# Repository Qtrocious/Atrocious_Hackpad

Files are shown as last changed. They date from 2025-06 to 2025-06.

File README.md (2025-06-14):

# Atrocious_Hackpad
A 3x3 macropad with a rotary encoder designed to function as a numpad and have certain layers for daily use

# But, but why tho
I saw hackpad as the perfect project for Highway to practice my skils i learned from Solder and i also learned fusion360! 
> It was painful

# CAD
CASE CAD (2)
# PCB
PCB (2)
# Schematic
SCHEMATIC (2)

# Screenshot of my case and how it'll fit together
Assembling

# BOM
| Item Name | Quantity |
|---|---|
| Cherry MX Switches |9|
| Blank DSA Keycaps |9|
| SK6812 MINI Leds |9|
| Through-hole 1N4148 Diodes |9|
| M3x16 Bolt |3| 
| M3 Heatset |3| 
| EC11 Rotary encoder |1|
| OLED .91" SSD1306 |1| 
| XIAO RP2040 |1|

@Atrocious on Slack!

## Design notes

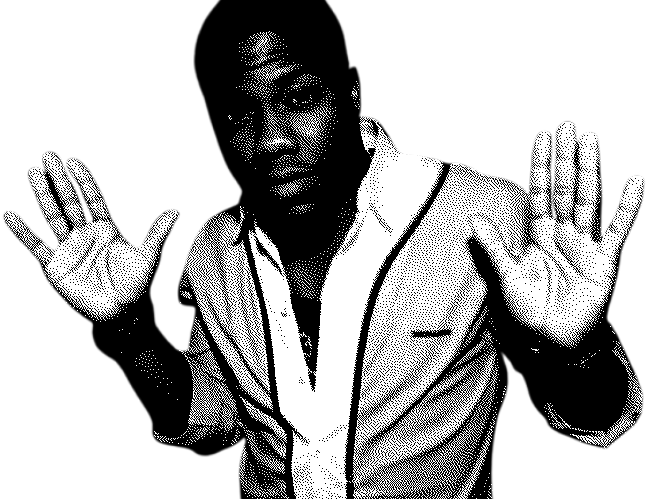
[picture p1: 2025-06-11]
firmware/KMK/kevin.bmp

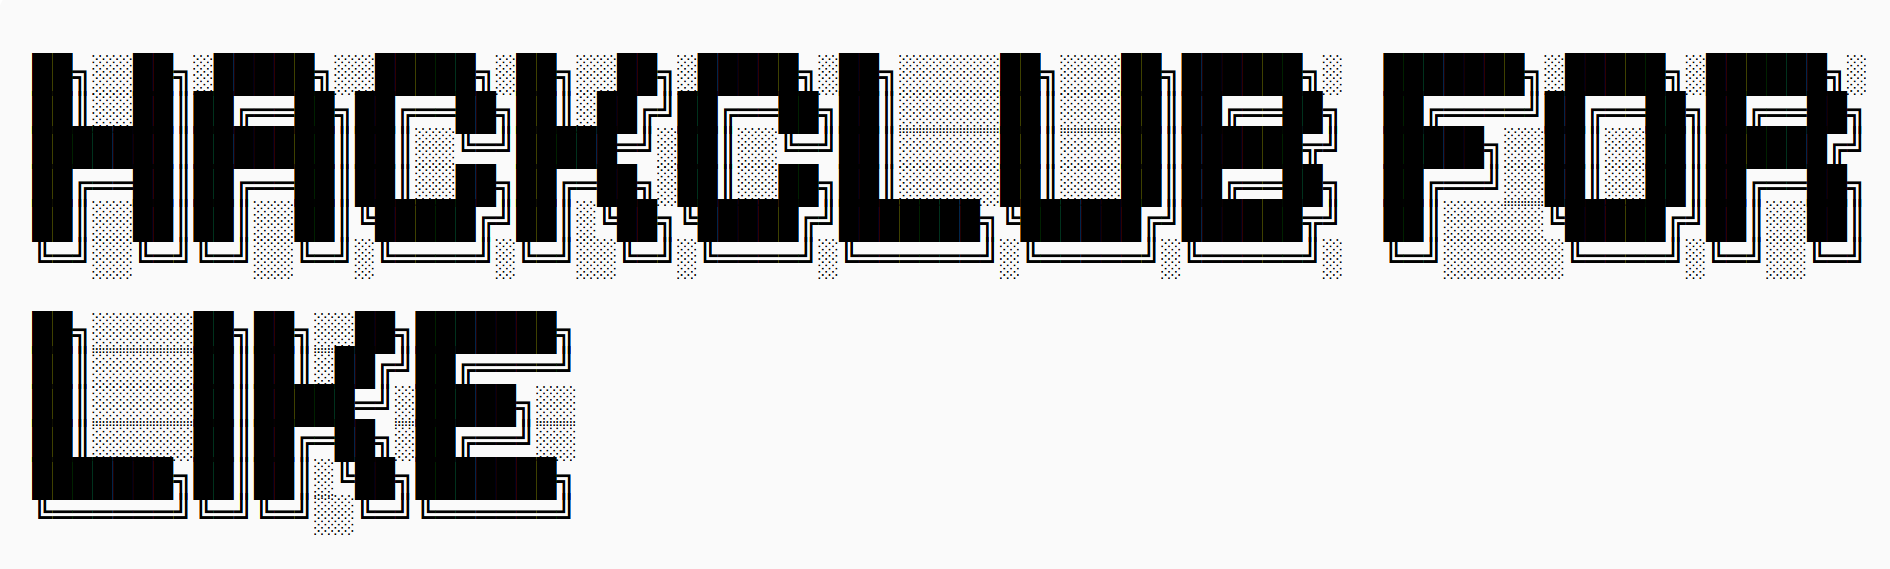
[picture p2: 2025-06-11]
firmware/KMK/hc.bmp

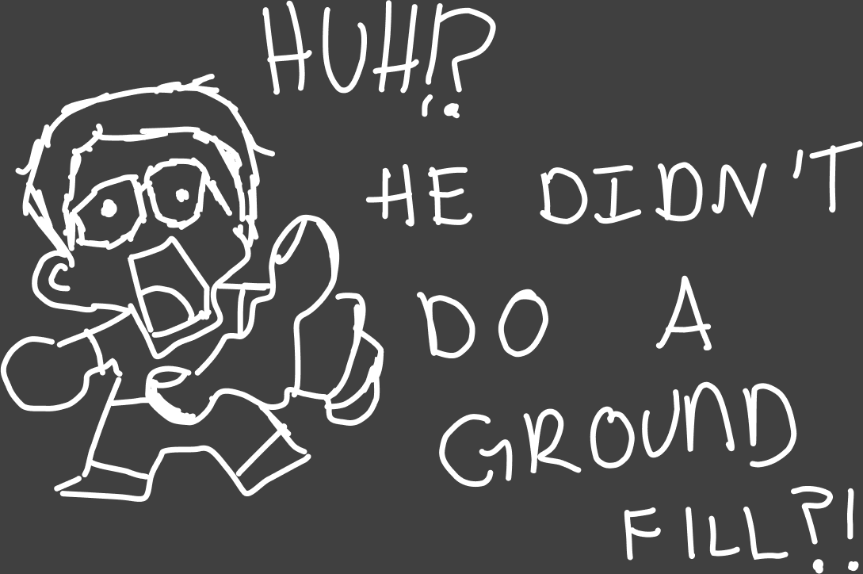
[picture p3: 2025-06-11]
firmware/KMK/me.bmp

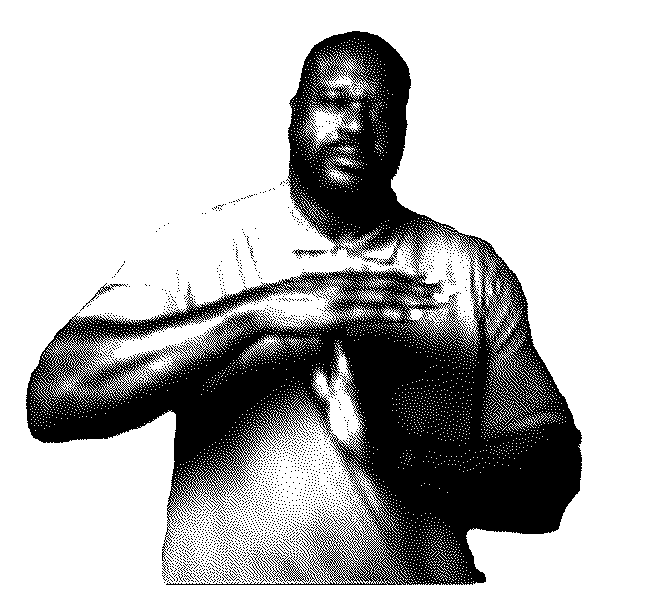
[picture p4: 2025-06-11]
firmware/KMK/oneil.bmp

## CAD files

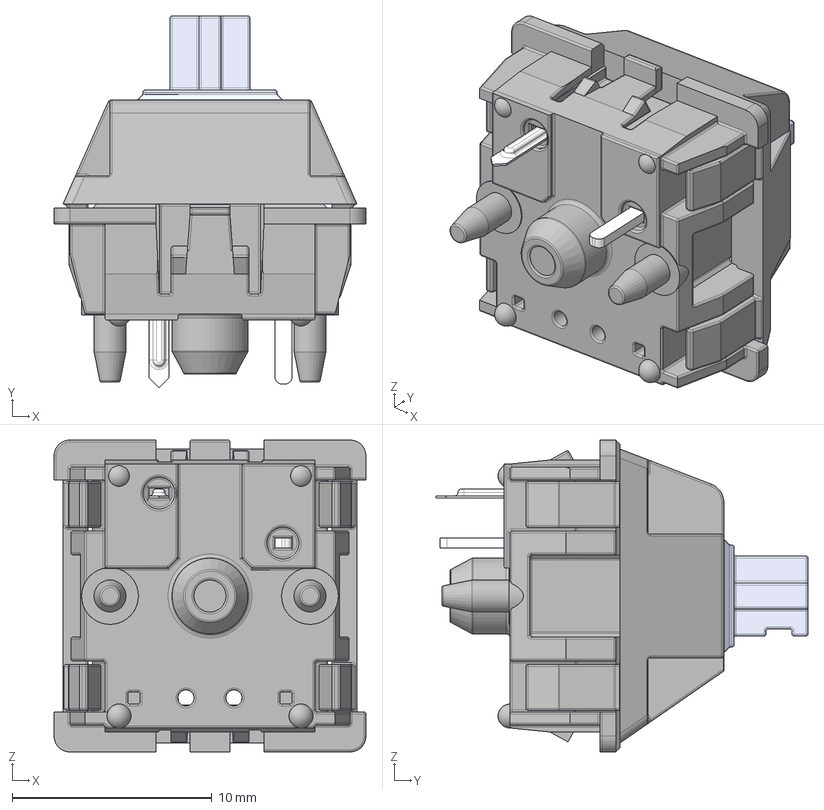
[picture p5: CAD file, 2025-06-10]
pcb/assets/Cherry MX Switch Base v2.step
15.6 x 18.6 x 15.6 mm
MX Öá °´¼ü¡ä_¨¹ ___¡§1
MX Öá ÖáÌå¨¢¨¬ _¡§¡é¡§__
MXÖá ÖáÌå µ×²¿ ¦Ì¡ Á2__Ä¬ÈÏ_¨¢2____¨¨_
Õë½Å___Ä¬ÈÏ__¨¨ _

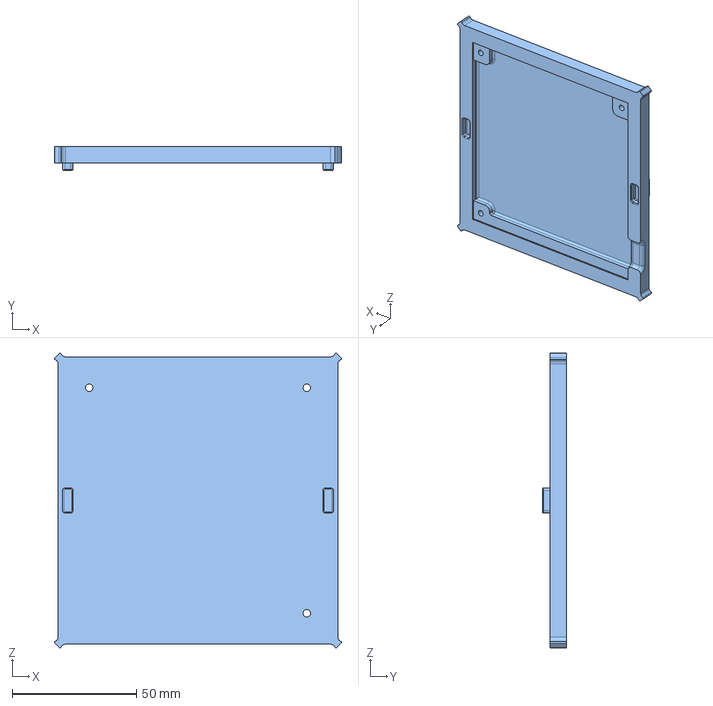
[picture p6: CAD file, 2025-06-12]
production/2_3_bottom cover___middle part.step
115.5 x 9.71 x 118.7 mm

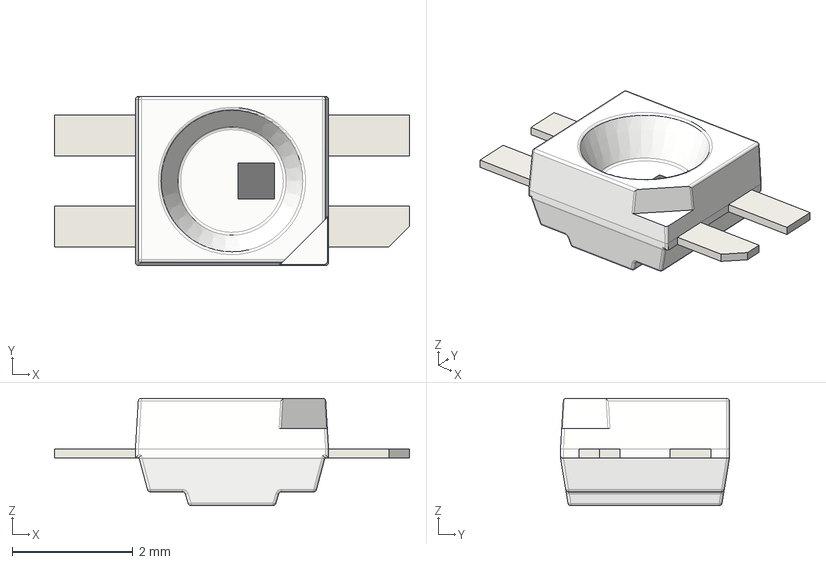
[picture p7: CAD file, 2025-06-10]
pcb/assets/LED_SK6812MINI-E v1.step
5.88 x 2.80 x 1.78 mm

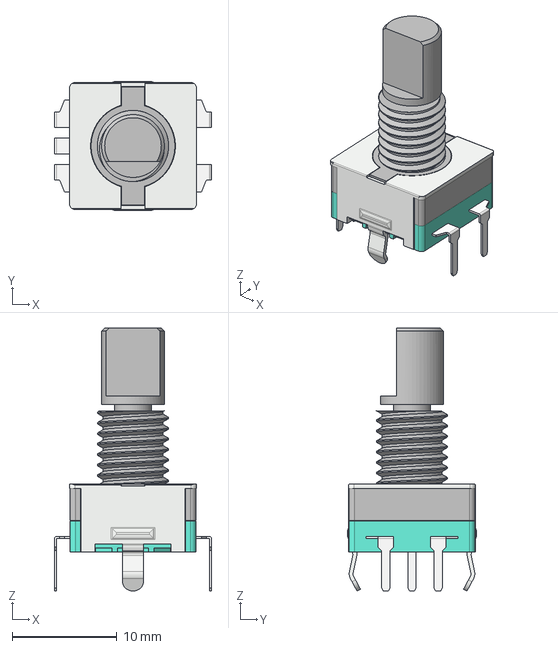
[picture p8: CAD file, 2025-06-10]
pcb/assets/EC11 v2.step
15.0 x 12.3 x 25.1 mm

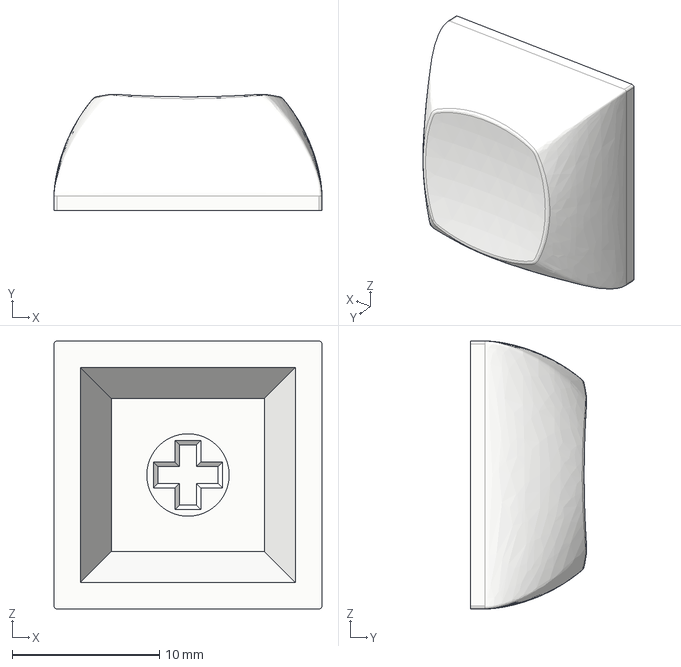
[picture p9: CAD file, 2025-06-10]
pcb/assets/DSA key caps.step
18.2 x 7.91 x 18.2 mm

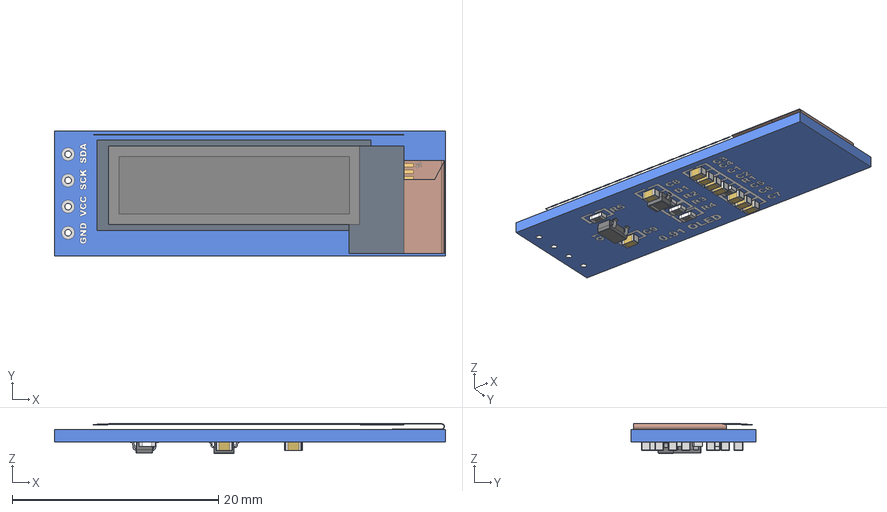
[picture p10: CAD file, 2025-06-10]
pcb/assets/0.91in OLED Module - Without Glass v1.step
37.9 x 12.1 x 2.93 mm
0.91in oled Module - Board
0.91in OLED - Folded Flush - Without Glass
0603 Capacitor x 9
0603 Resistor x 5
SOT23-3
Diode (SOD-323)

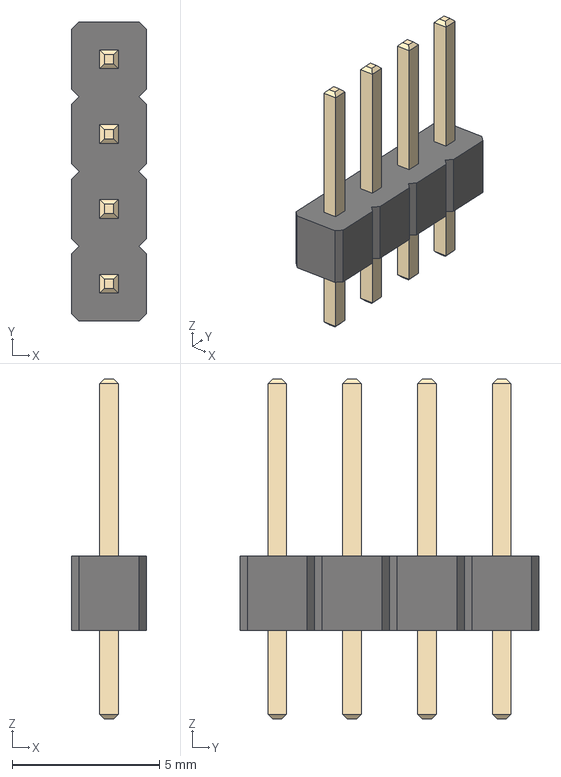
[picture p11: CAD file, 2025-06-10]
pcb/assets/PinHeader_1x04_P2.54mm_Vertical.step
2.54 x 10.2 x 11.5 mm

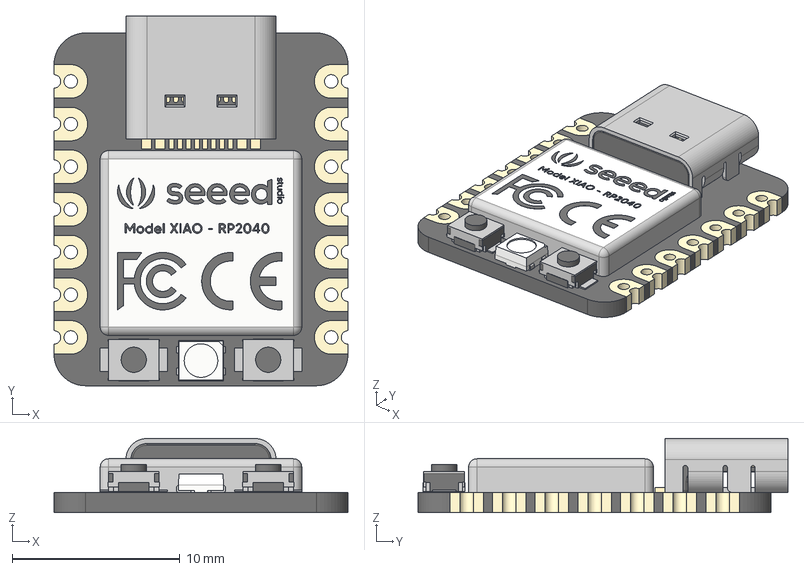
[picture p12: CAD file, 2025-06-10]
pcb/assets/Seeed Studio XIAO RP2040 v26 v1.step
17.5 x 22.0 x 4.40 mm
type-c v2
smd_button v3
DOUT
DIN
VSS
VDD
smd_button v3(Mirror)

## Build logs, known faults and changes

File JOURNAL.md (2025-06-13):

---
title: "Atrocious_Hackpad"
author: "@Qtrocious"
description: "A 9 key macropad with a rotary encoder, 9 sk6812 leds and a oled display"
created_at: "2025-05-28"
---

**Total time spent: 41.5 hours**

> So for clarification, didn't realized i needed to journal for a starter project (dumb from my part ik) but thankfully (and luckily) i did have a local repo that i had from the beginning, i'll attach an screenshot to each day that i commit something TT

Clarification

# May 28 :suspect:



After doing Solder, i thought that i could do the hackpad YSWS. 
I didn't do the tutorial first, i just kinda based what i did from there. So here it goes:

For a long time i wanted to mess around with a display so this was the perfect opportunity. I wanted to use all the 16 keyswitches, without thinking on how it would be placed on the pcb.
 
Then, i realized, i didn't want to make it big or sort of medium sized. I wanted it to be small, compact, not taking too much space from my desk.

So i ended up with the choice of using 9 keyswitches for the hackpad, an oled and also wanted to use the leds, just didn't know how to connect them.

Time Spent: 2.5 hours

# May 29 :suspect: 



After skeeming through the hackpad channel, i learned how to connect the rotary encoder that i could do a matrix + connecting the leds in series so i didn't use all of the gpios, that i could use global labels in kicad so i didn't need to connect them directly. 
> WHAT, THAT'S GENIUS :interrobang:

Also included the rotary encoder and oled display. Ended up with a :goat: ed schematic 

Og schematic OMFG1

Time Spent: 3 hours

# May 31 :suspect:

> night owl :sigma_male:

With the schematic done, i placed the components to the pcb tab to resemble a macropad.

I didn't really sketch or made a certain design for the pcb, so i just went with it and kinda liked it!

Learned from Solder and did some rounded corners, might have over did it tho. 

Finished for the day by starting to trace the connections, although i didn't want to use a lot of vias, this took a lot of time and it was super late so i left it mid tracing 



Time spent: 5 hours

# June 1 :rage1:



Sooo... i didn't like the shape after all, so i changed to have less rounded things, finally added some ground fills, looks so professional!

3d view

Time Spent: 2 hours

# June 2 :rage3:



Started to add silkscreen art, mainly to personalize my pcb further, i wanted to make it mine, to show what i liked, learned that i could draw on figma and export it as svg. 

I saw a super cool [silkscreen art](https://lh4.googleusercontent.com/proxy/1_U3g3KRv54jqYMfxqYlnqbbxwsGXWIzcXYJClNF3SlAx20Lz0C3ZUfjKaGJKFvePmdQwYVAVtmIgr0zbJFWp6T9adAC0VlgzglczDJyZidVwr7j) that i wanted to recreate since making Solder and discovered a nice little tool called [Ditherlicious](https://29a.ch/ditherlicious/), it let's you apply the same dither effect on images. 
> BTW this is NOT recommended, Kicad makes individual objects for each point, so avoid using multiple ones with the same effect

Pcb with silkscreen

So of course i wanted to be happy and added this:


Time Spent: 4 hours

# June 5 :rage4:
I <sub>AGAIN</sub> changed the pcb outline, i wanted to fit the silkscreen art without having to worry about where to place it, so i just made the outline be a rectangle with rounded courners 

Pcb with new silkscreen art
PCB SILKSCREEN FINAL DESIGN

And also, found out you can actually add the rotary encoder to the matrix
Correct schematic

Time Spent: 3.5 hours

# June 6 :rage4:
> I have a fusion version that goes from June 6, i imported the Orpheuspad on june 4 but since i didn't have anything else from that day i just went from june 6

Fusion

I started the design on Fusion by first doing the basic layout of the keys and making a basic case

Basic 3d case

But i didn't want to leave it at that, so, based on how Orpheuspad designed the heatset inserts and being slightly inclined, i decided i wanted to integrate that to my design.
> AND THAT WAS A PAIN IN THE BUTT! :hurtrealbad:

Time Spent: 3 hours

# June 7 :goberserk:
fusion june 7

By measuring the dimensions in kicad and looking at the examples of the key switch on the guide, i made the sketches in fusion and on a notebook to have both in digital and physical.

I needed to add the holes for the rotary encode and the oled so this are the sketches i made, to get the measurements just right.

I learned so much actually, it felt so amazing when i extruded a sketch and the cut or join action was right, so satisfying!

Sketches
> This sketches were made from june 7 to june 8
 
Time Spent: 4 hours

# June 8 Part 1 :goberserk:
Fusion June 8 hours
> this is a late night session from june 7, night owl v2

So from the late night session i started to work on putting the holes for the oled and rotary encoder, added the mounting holes for the screws, also using the ones from the pcb.

Fusion June 7

Time Spent: 2 hours

# June 8 Part 2 :finnadie:
Fusion June 8 hours v2

Wanted to make it fit perfectly, didn't want thin walls so the heatset inserts have enough to go around melting the 3d print

Bad holes
> This was an awful experience, it was fun

So after a full afternoon of making the holes both for the screws and heatset inserts, i added the covers for the heatset insert holes, so they are not visible and they fit!
They fit

Time Spent: 5 hours 
# June 9 :feelsgood:
I've not been mentioning the bottom cover, the reason is it was an easier process, almost an immediate process 

> The usb-c hole is in the wrong orientation lol, but i changed it later

I was finally finishing the top cover design, added some text, and made it so it looks not so plain
Fusion June 9

That's also the case for the bottom cover, and if you see close enough, at the side of the usb c port, there's a support designed for the pcb due to only having 3 mounting holes, which would make it unstable, so that's the reason it's there.



And to finish it, the inclination that also function as the support for the macorpad!



I've added some text and as you see theres the holes for the screws and honestly, i'm really proud of this, i learned so much and this has only sparked a motivation in me to make more projects, thank you! 

Time Spent: 4 hours
# June 10 :godmode:

So this is the final design



I wanted to go with black on the top and inclined part because if it gets dirty it doesn't show as much, and the blue in the middle so it resembles Tron!

For the code, i made 4 layers, each one with different functions.
```
keyboard.keymap = [
 
    [ #LAYER 0: NUMPAD
     KC.N7, KC.N8, KC.N9, RAISE,
     
     KC.N4, KC.N5, KC.N6,

     KC.N1, KC.N2, KC.N3
    ],
    
    [ #LAYER 1: Media Keys
     KC.NO, KC.BRIU, KC.NO, MIDDLE,

     KC.MPRV, KC.MPLY, KC.MNXT,

     KC.NO, KC.BRID, KC.NO
    ],

    [ #LAYER 2: DAILY [TBD, will think of it when i have it in-person!]
     KC.N7, KC.N8, KC.N9, MIDDLER ,

     KC.N4, KC.N5, KC.N6,

     KC.N1, KC.N2, KC.N3
    ],
    
    [ #LAYER 3: LEDs animation 
     KC.RGB_MODE_KNIGHT, KC.RGB_MODE_SWIRL, KC.RGB_MODE_BREATHE, BASE,
     
     KC.RGB_HUD, KC.RGB_ANI, KC.RGB_HUI,
     
     KC.N1, KC.RGB_AND, KC.RGB_TOG
    ],
]
```
and for each layer i wanted the oled to display different stuff, to differentiate each layer

```
display.entries = [
    ImageEntry(image="me.bmp", x=0, y=0, layer=0),
    ImageEntry(image="kevin.bmp", x=0, y=0, layer=1), 
    ImageEntry(image="oneil.bmp", x=0, y=0, layer=2), 
    ImageEntry(image="hc.bmp", x=0, y=0, layer=3), 
    TextEntry(text="Layer 0", x_anchor="T", y_anchor="R", layer=0),
    TextEntry(text="Layer 1", x_anchor="T", y_anchor="R", inverted=True, layer=1),
    TextEntry(text="Layer 2", x_anchor="T", y_anchor="R", inverted=True, layer=2),
    TextEntry(text="Layer 3", x_anchor="T", y_anchor="R", inverted=True, layer=3),
]
```

As for the rotary encoder, for now it will only increase or decrease the volume

```
encoder_handler.map = [
    ((KC.VOLD, KC.VOLU),), #Layer 0 NUMPAD
]
```

Time Spent: 3 hours 

# June 12 :godmode:
Added some supports? Idk but i added this to make the assembly easier




Time Spent: 0.5 hours
Video of the assembling 

https://github.com/user-attachments/assets/44710b4c-f038-4628-ad3c-8864bbcb4045

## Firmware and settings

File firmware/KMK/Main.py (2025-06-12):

print("Starting")

import board
import busio
from kmk.kmk_keyboard import KMKKeyboard
from kmk.keys import KC
from kmk.scanners import DiodeOrientation
from kmk.modules.layers import Layers
from kmk.extensions.rgb import RGB
from kmk.modules.encoder import EncoderHandler
from kmk.extensions.media_keys import MediaKeys
from kmk.modules.mouse_keys import MouseKeys
from kmk.extensions.display import Display, TextEntry, ImageEntry
from kmk.extensions.display.ssd1306 import SSD1306
from kmk.modules.tapdance import TapDance

keyboard = KMKKeyboard()


keyboard.row_pins = (board.GP3, board.GP4, board.GP2)
keyboard.col_pins = (board.GP27, board.GP28, board.GP29)
keyboard.diode_orientation = DiodeOrientation.COL2ROW

encoder_handler = EncoderHandler()

keyboard.modules.append(Layers())
keyboard.modules.append(encoder_handler)
keyboard.modules.append(MediaKeys())
keyboard.modules.append(MouseKeys())
keyboard.modules.append(TapDance())

encoder_handler.pins = ((board.GP0, board.GP1, None),)

#RGB
rgb = RGB(pixel_pin=board.GP26, 
          num_pixels=9, 
          rgb_order=(1,0,2),
          
          )

keyboard.extensions.append(rgb)

i2c_bus = busio.I2C(board.GP_SCL, board.GP_SDA)
driver = SSD1306(i2c=i2c_bus)

display = Display(
    # Mandatory:
    display=driver,
    # Optional:
    width=128, # screen size
    height=32, # screen size
    flip = False, # flips your display content
    flip_left = False, # flips your display content on left side split
    flip_right = False, # flips your display content on right side split
    brightness=1, # initial screen brightness level
)


display.entries = [
    ImageEntry(image="me.bmp", x=0, y=0, layer=0),
    ImageEntry(image="kevin.bmp", x=0, y=0, layer=1), 
    ImageEntry(image="oneil.bmp", x=0, y=0, layer=2), 
    ImageEntry(image="hc.bmp", x=0, y=0, layer=3), 
    TextEntry(text="Layer 0", x_anchor="T", y_anchor="R", layer=0),
    TextEntry(text="Layer 1", x_anchor="T", y_anchor="R", inverted=True, layer=1),
    TextEntry(text="Layer 2", x_anchor="T", y_anchor="R", inverted=True, layer=2),
    TextEntry(text="Layer 3", x_anchor="T", y_anchor="R", inverted=True, layer=3),
]
keyboard.extensions.append(display)

TRANS = KC.TRNS
RAISE =   KC.LT(1, KC.TD(KC.B, KC.A), prefer_hold=True, tap_interrupted=False, tap_time=1000)
MIDDLE =  KC.LT(2, KC.TD(KC.B, KC.A), prefer_hold=True, tap_interrupted=False, tap_time=1000)
MIDDLER = KC.LT(3, KC.TD(KC.B, KC.A), prefer_hold=True, tap_interrupted=False, tap_time=1000)
BASE =    KC.LT(0, KC.TD(KC.B, KC.A), prefer_hold=True, tap_interrupted=False, tap_time=1000)
keyboard.keymap = [
 
    [ #LAYER 0: NUMPAD
     KC.N7, KC.N8, KC.N9, RAISE,
     
     KC.N4, KC.N5, KC.N6,

     KC.N1, KC.N2, KC.N3
    ],
    
    [ #LAYER 1: Media Keys
     KC.NO, KC.BRIU, KC.NO, MIDDLE,

     KC.MPRV, KC.MPLY, KC.MNXT,

     KC.NO, KC.BRID, KC.NO
    ],

    [ #LAYER 2: DAILY [TBD, will think of it when i have it in-person!]
     KC.N7, KC.N8, KC.N9, MIDDLER ,

     KC.N4, KC.N5, KC.N6,

     KC.N1, KC.N2, KC.N3
    ],
    
    [ #LAYER 3: LEDs animation 
     KC.RGB_MODE_KNIGHT, KC.RGB_MODE_SWIRL, KC.RGB_MODE_BREATHE, BASE,
     
     KC.RGB_HUD, KC.RGB_ANI, KC.RGB_HUI,
     
     KC.N1, KC.RGB_AND, KC.RGB_TOG
    ],
]


encoder_handler.map = [
    ((KC.VOLD, KC.VOLU),), # any layer
]

if __name__ == '__main__':
    keyboard.go()

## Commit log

2025-06-10 Added what i could for now
    Will add what's left
    [0.91in OLED Module - Without Glass v1.step, 2_3_bottom cover___middle part.step, Atrocious_Hackpad.kicad_sch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]
2025-06-11 Completed the requirements to submit
    [Atrocious_Hackpad.kicad_sch]
2025-06-12 Updated inclined part
    [2_3_bottom cover___middle part.step]
